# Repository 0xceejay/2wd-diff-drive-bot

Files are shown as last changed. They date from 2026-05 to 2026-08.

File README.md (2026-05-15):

# 2WD Differential Drive Bot

A work-in-progress 2-wheel differential drive robot built with ROS 2, Gazebo,
micro-ROS, and ESP32 firmware.

The project currently includes the robot description, Gazebo simulation launch
files, joystick teleoperation, a micro-ROS agent launch flow, and PlatformIO
firmware for the ESP32 controller.

## Repository layout

```text
2wd-diff-drive-bot/
|-- firmware/
|   |-- bot_firmware/        # ESP32 PlatformIO firmware
|-- src/
|   |-- bot_bringup/         # ROS 2 launch files and teleop config
|   |-- bot_description/     # URDF, xacro files, meshes, and Onshape export
|-- LICENSE
|-- README.md
```

## Main parts

| Path | Purpose |
| --- | --- |
| `src/bot_description` | Robot model, URDF/xacro files, Gazebo tags, meshes, and Onshape export workflow. |
| `src/bot_bringup` | Current launch flows for joystick teleop, micro-ROS, and Gazebo simulation. |
| `firmware/bot_firmware` | ESP32 firmware that connects to ROS 2 through micro-ROS over Wi-Fi. |

## Requirements

- ROS 2 Jazzy
- Gazebo / `ros_gz_sim` and `ros_gz_bridge`
- `xacro`
- `robot_state_publisher`
- `joy`
- `teleop_twist_joy`
- `micro_ros_agent`
- PlatformIO for the ESP32 firmware

## Build the ROS 2 workspace

From the repository root:

```bash
colcon build
source install/setup.bash
```

To build one package:

```bash
colcon build --packages-select bot_description
colcon build --packages-select bot_bringup
```

## Run simulation

```bash
source install/setup.bash
ros2 launch bot_bringup sim.launch.py
```

This starts Gazebo, publishes the robot description, spawns the robot, and
bridges the main Gazebo topics to ROS 2.

## Run the physical robot flow

Start joystick teleop and the micro-ROS agent:

```bash
source install/setup.bash
ros2 launch bot_bringup robot.launch.py
```

The ESP32 firmware must be flashed and configured with the ROS 2 computer's IP
address in `firmware/bot_firmware/include/wifi_secrets.hpp`.

## Firmware

From the repository root:

```bash
pio run -d firmware/bot_firmware
pio run -d firmware/bot_firmware --target upload
```

See `firmware/bot_firmware/README.md` for firmware setup, Wi-Fi configuration,
and micro-ROS notes.

## Documentation

- `src/bot_description/README.md`: robot description package notes.
- `src/bot_description/onshape/README.md`: Onshape export and post-processing
  workflow.
- `src/bot_bringup/README.md`: launch files and startup flows.
- `firmware/bot_firmware/README.md`: ESP32 firmware setup and commands.

## License

This project is licensed under the MIT License. See `LICENSE`.

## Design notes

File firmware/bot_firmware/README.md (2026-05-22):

# bot_firmware

PlatformIO firmware for the ESP32 controller on the 2-wheel differential drive
robot.

The firmware uses micro-ROS over Wi-Fi to connect the ESP32 to the ROS 2
computer. It subscribes to `/cmd_vel`, reads incoming
`geometry_msgs/msg/Twist` messages, and calculates left/right wheel velocity
targets from the robot geometry.

## Hardware and framework

- Board: ESP32 DOIT DevKit V1
- Framework: Arduino
- Build system: PlatformIO
- micro-ROS distro: Jazzy
- micro-ROS transport: Wi-Fi
- Serial monitor speed: `115200`
- Upload speed: `921600`
- micro-ROS agent UDP port: `8888`

These settings live in `platformio.ini`.

## Project layout

```text
bot_firmware/
|-- include/
|   |-- wifi_secrets.hpp  # Local Wi-Fi and agent IP settings
|   |-- README
|-- lib/
|   |-- Encoders/         # HC-020K wheel encoder helper
|   |-- Motors/           # TB6612FNG motor driver helper
|   |-- README
|-- src/
|   |-- main.cpp          # ESP32 micro-ROS node
|-- test/                 # PlatformIO tests
|-- platformio.ini
`-- README.md
```

## Local Wi-Fi settings

`src/main.cpp` expects a local header at:

```text
include/wifi_secrets.hpp
```

It should define:

```cpp
#define WIFI_SSID "your_wifi_name"
#define WIFI_PASSWORD "your_wifi_password"

#define AGENT_IP_1 192
#define AGENT_IP_2 168
#define AGENT_IP_3 1
#define AGENT_IP_4 10
```

The `AGENT_IP_*` values should match the IP address of the computer running the
micro-ROS agent.

Keep this file local because it contains Wi-Fi credentials.

## Build

From this folder:

```bash
pio run
```

Or from the workspace root:

```bash
pio run -d firmware/bot_firmware
```

## Upload

From this folder:

```bash
pio run --target upload
```

Or from the workspace root:

```bash
pio run -d firmware/bot_firmware --target upload
```

## Serial monitor

```bash
pio device monitor
```

The firmware prints the calculated left and right wheel velocities when it
receives `/cmd_vel` messages.

## Run with ROS 2

Start the micro-ROS agent on the ROS 2 computer:

```bash
ros2 launch bot_bringup micro_ros.launch.py
```

That launch file starts the agent with UDP on port `8888`, matching the firmware.

<!-- To start the robot bringup flow with teleop and the micro-ROS agent:

```bash
ros2 launch bot_bringup robot.launch.py
``` -->

## Subscribed topic

| Topic | Type | Purpose |
| --- | --- | --- |
| `/cmd_vel` | `geometry_msgs/msg/Twist` | Command linear and angular velocity |

The current firmware computes wheel velocity targets using:

```text
left = linear.x - (wheel_base / 2) * angular.z
right = linear.x + (wheel_base / 2) * angular.z
```

Current geometry constants:

- Wheel radius: `0.033 m`
- Wheel base: `0.1443 m`

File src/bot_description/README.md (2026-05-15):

# bot_description

ROS 2 description package for the 2-wheel differential drive robot.

This package owns the robot model used by RViz, Gazebo, and launch files in
`bot_bringup`. It contains the URDF/xacro files, mesh assets, and the Onshape
export workflow used to regenerate the model.

## Package contents

```text
bot_description/
|-- meshes/             # STL mesh assets used by the URDF
|-- onshape/            # Onshape export config and post-processing script
|-- urdf/
|   |-- bot.urdf        # Generated base URDF from Onshape
|   |-- bot.urdf.xacro  # Main robot description entry point
|   |-- gazebo.xacro    # Gazebo materials, friction, and simulation plugins
|-- CMakeLists.txt
|-- package.xml
```

## Main description file

`urdf/bot.urdf.xacro` is the entry point for the robot description.

It currently includes:

- `urdf/bot.urdf`: the generated robot links, joints, and mesh references.
- `urdf/gazebo.xacro`: Gazebo-specific materials, friction values, differential
  drive plugin configuration, and joint state publishing.

## Build

From the workspace root:

```bash
colcon build --packages-select bot_description
source install/setup.bash
```

## Run in simulation

This package provides the description assets, but the launch flow lives in
`bot_bringup`.

The usual flow is:

```bash
colcon build
source install/setup.bash
ros2 launch bot_bringup sim.launch.py
```

## Regenerate from Onshape

The base URDF and mesh assets are generated from the files in `onshape/`.

From `src/bot_description/onshape`:

```bash
onshape-to-robot . && python3 postprocess.py
```

The post-processing script copies STL files into `meshes/`, writes the processed
URDF to `urdf/bot.urdf`, simplifies selected collision geometry, and injects the
`base_link` root link.

See `onshape/README.md` for the Onshape export notes.

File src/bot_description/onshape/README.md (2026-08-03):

# Onshape export

This folder contains the files used to regenerate the robot's base URDF and
mesh assets from Onshape.

CAD assembly: [Onshape](https://cad.onshape.com/documents/292c33a7f0f854a3cdb21f44/w/3cfe75fb330dfc627e8355b6/e/a29efea0b989aa0e985d95df)

The generated files are copied into the parent `bot_description` package:

- `../urdf/bot.urdf`
- `../meshes/*.stl`

## Files

- `config.json`: configuration used by `onshape-to-robot`.
- `postprocess.py`: cleanup script that adapts the generated model for this ROS
  2 package and Gazebo simulation.

## Export workflow

Run this command from this folder:

```bash
onshape-to-robot . && python3 postprocess.py
```

`onshape-to-robot` reads `config.json`, exports the `robot` assembly from
Onshape, and creates a temporary `robot.urdf` plus an `assets/` folder.

`postprocess.py` then:

- writes the processed URDF to `../urdf/bot.urdf`
- copies exported STL files into `../meshes/`
- changes mesh paths from `assets/` to `meshes/`
- adds `base_link` as the root link with a fixed joint to `chassis`
- removes collision geometry from small/internal parts
- replaces selected collision meshes with simple box, cylinder, or sphere shapes
- adjusts wheel collision orientation and offsets
- adds light damping and friction to the caster swivel joint
- removes the temporary `robot.urdf` and `assets/` folder

## Notes

This workflow overwrites the generated URDF and refreshes mesh files in the
package. After regenerating, check the robot in simulation with:

```bash
colcon build
source install/setup.bash
ros2 launch bot_bringup sim.launch.py
```

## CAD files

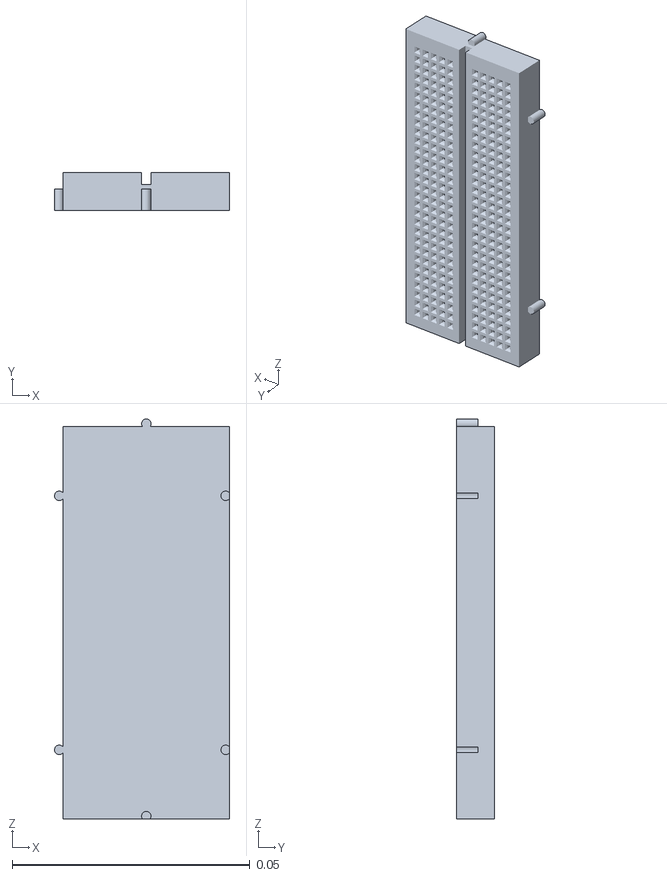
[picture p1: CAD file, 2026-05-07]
src/bot_description/meshes/main_half_size_board.stl
0.0368 x 0.008 x 0.0841

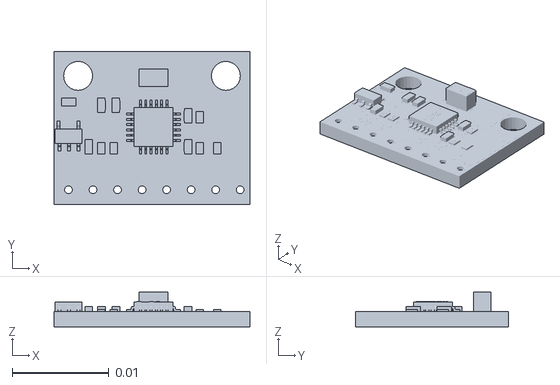
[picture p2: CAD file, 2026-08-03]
src/bot_description/meshes/mpu6050.stl
0.0203 x 0.0158 x 0.00362

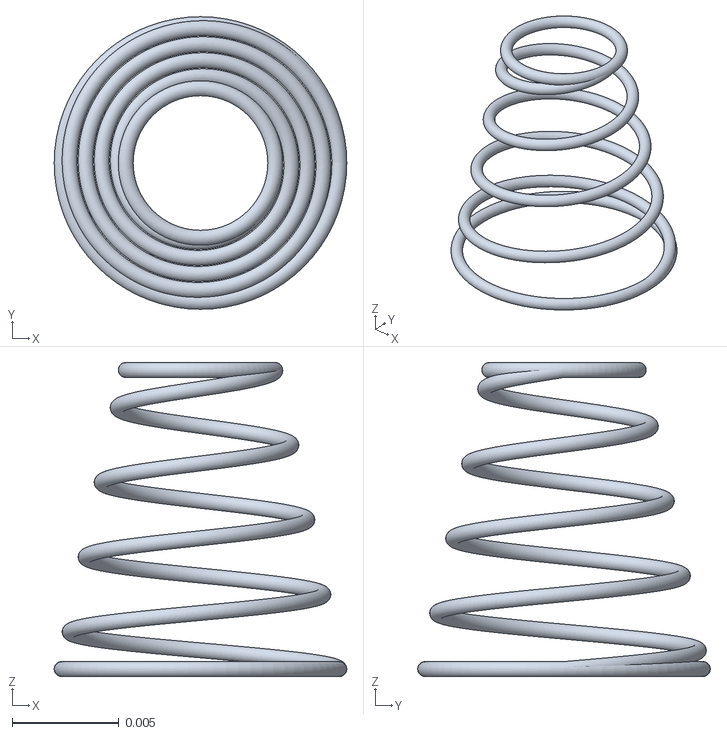
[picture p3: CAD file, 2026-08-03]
src/bot_description/meshes/contacto_helice_v2_0.stl
0.0137 x 0.0137 x 0.0147

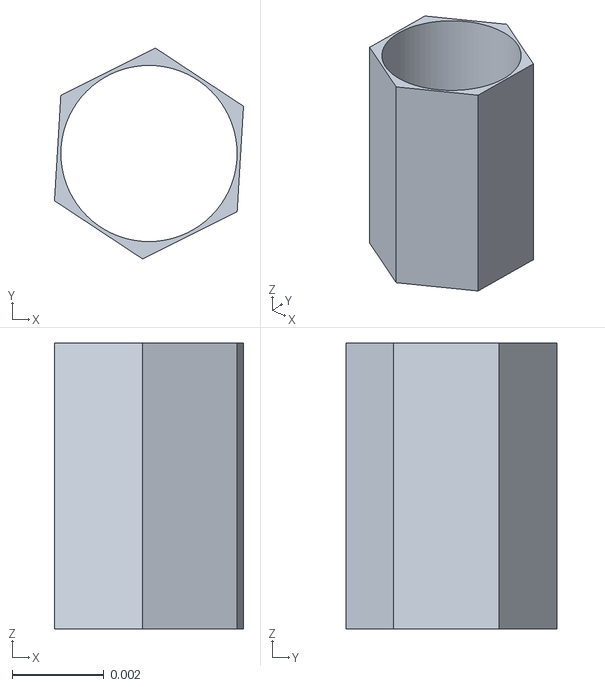
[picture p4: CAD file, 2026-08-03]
src/bot_description/meshes/spacer.stl
0.00413 x 0.00461 x 0.00625

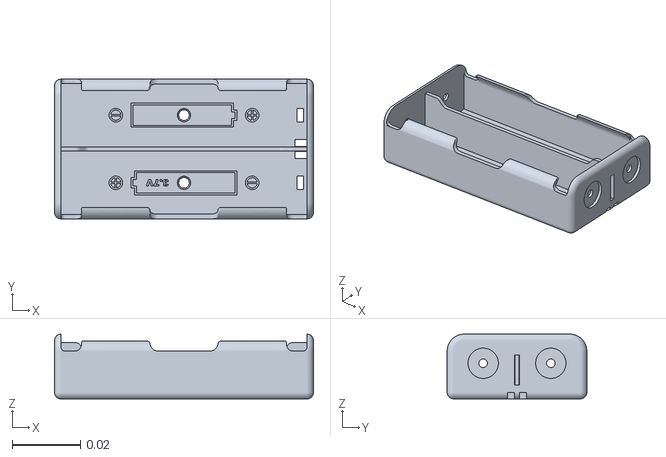
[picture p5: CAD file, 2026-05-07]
src/bot_description/meshes/porta_baterias_2x18650.stl
0.076 x 0.041 x 0.019

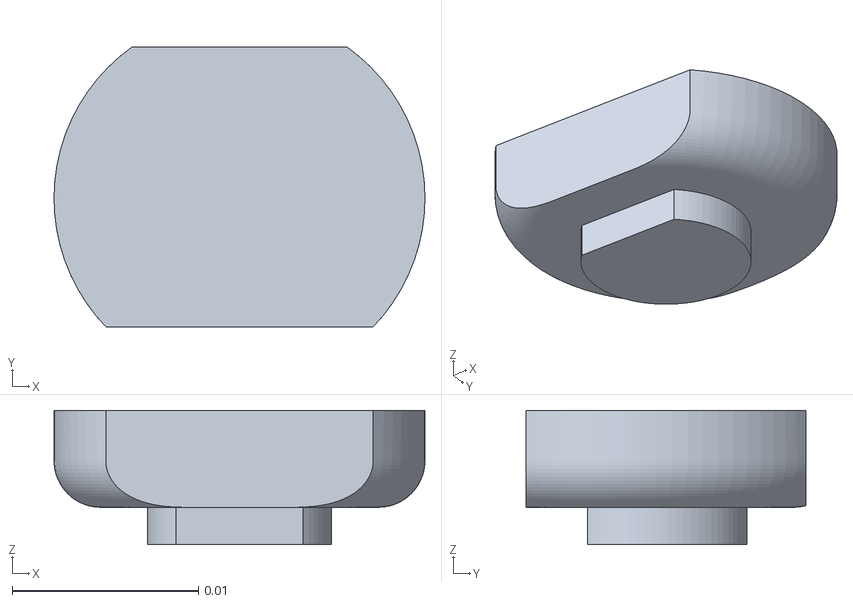
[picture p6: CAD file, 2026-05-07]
src/bot_description/meshes/tt_motor_3777_v10__6.stl
0.0199 x 0.015 x 0.0072

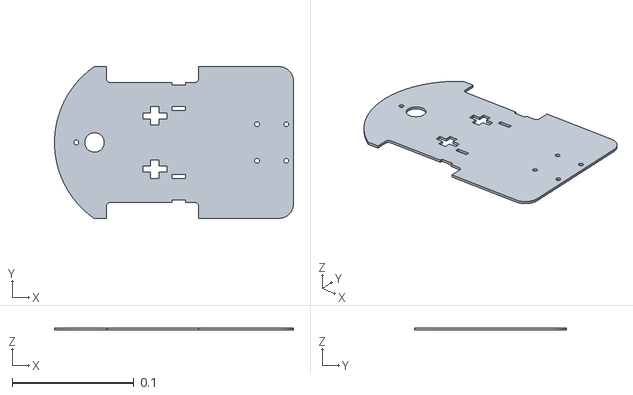
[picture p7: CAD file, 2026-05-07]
src/bot_description/meshes/chassis.stl
0.197 x 0.125 x 0.002

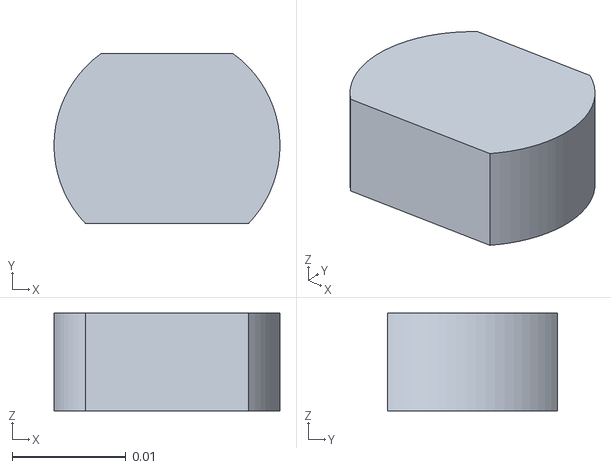
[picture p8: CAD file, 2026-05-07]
src/bot_description/meshes/tt_motor_3777_v10__4.stl
0.0199 x 0.015 x 0.0086

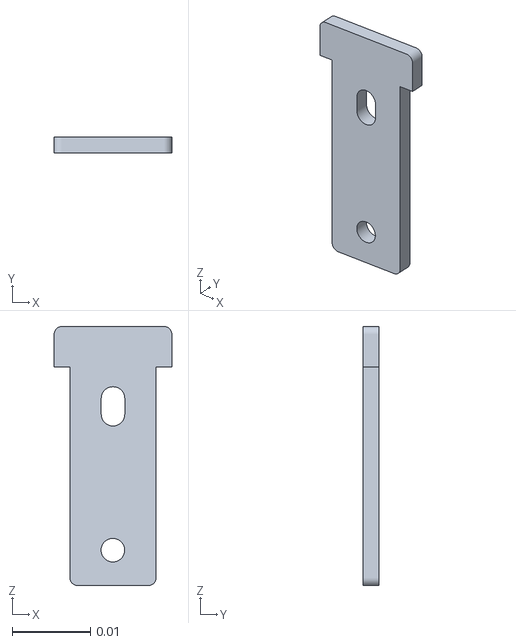
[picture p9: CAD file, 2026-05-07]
src/bot_description/meshes/motor_holders.stl
0.015 x 0.002 x 0.033

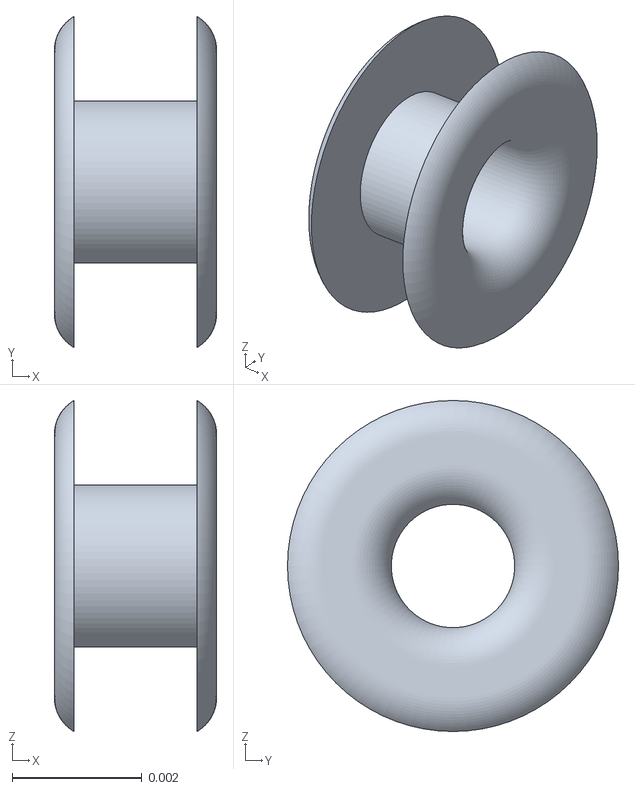
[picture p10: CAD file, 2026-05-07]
src/bot_description/meshes/remache_v1_0.stl
0.0025 x 0.0051 x 0.0051

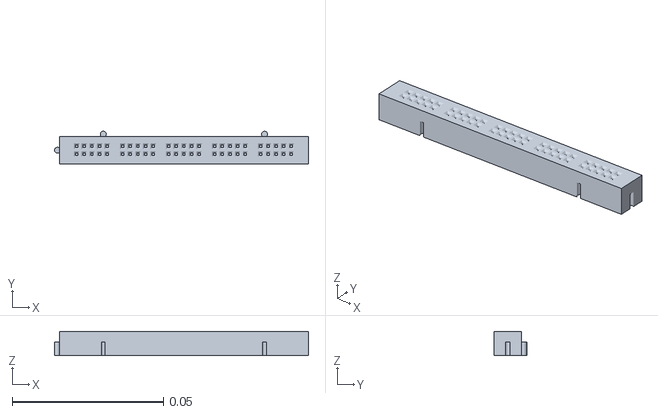
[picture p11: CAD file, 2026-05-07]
src/bot_description/meshes/half_size_side_rail.stl
0.0841 x 0.0108 x 0.008

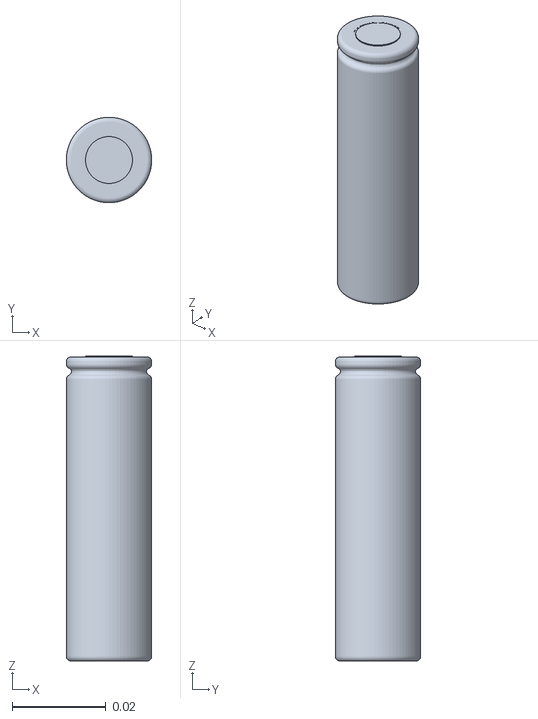
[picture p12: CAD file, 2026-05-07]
src/bot_description/meshes/bateria_18650.stl
0.0182 x 0.0182 x 0.065

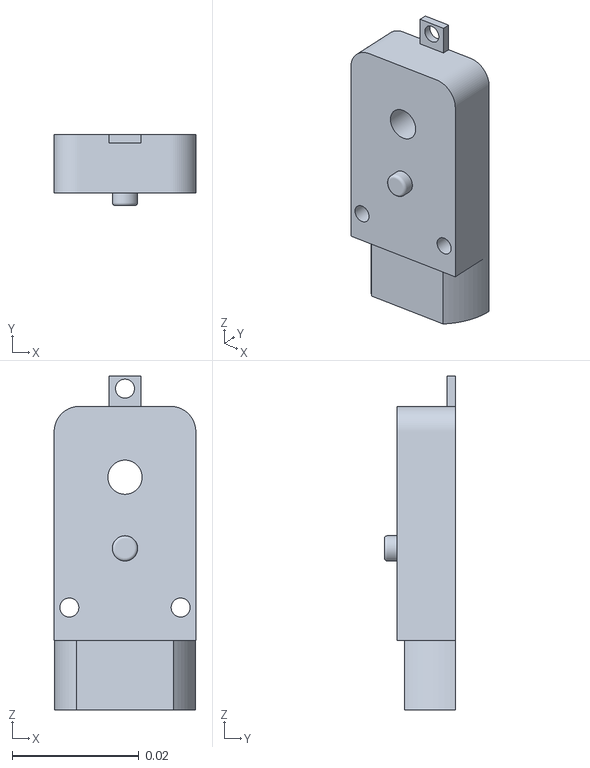
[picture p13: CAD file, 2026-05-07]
src/bot_description/meshes/tt_motor_3777_v10.stl
0.0224 x 0.0113 x 0.0528

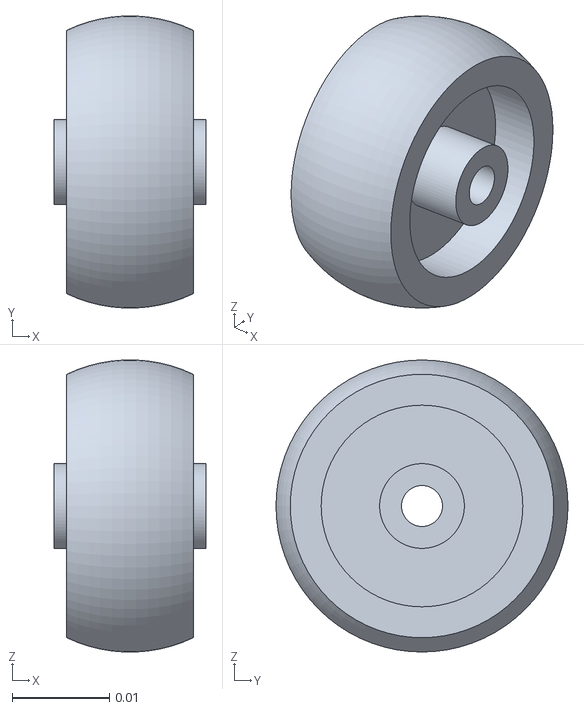
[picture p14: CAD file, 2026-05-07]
src/bot_description/meshes/caster_40mm_wheel_30mm_01.stl
0.0156 x 0.03 x 0.03

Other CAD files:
src/bot_description/meshes/tt_motor_3777_v10__3.stl
src/bot_description/meshes/tt_motor_3777_v10__2.stl
src/bot_description/meshes/tt_motor_3777_v10__5.stl
src/bot_description/meshes/caster_40mm_wheel_support_01.stl
src/bot_description/meshes/caster_40mm_swivel_plate_01.stl
src/bot_description/meshes/contacto_plano_v1_0.stl
src/bot_description/meshes/tt_motor_3777_v10__7.stl
src/bot_description/meshes/tt_motor_3777_v10__8.stl
src/bot_description/meshes/wheel.stl

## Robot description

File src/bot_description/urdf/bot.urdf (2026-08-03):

<?xml version="1.0" ?>
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
<robot name="bot">
  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
  <link name="base_link"/>
  <joint name="base_joint" type="fixed">
    <parent link="base_link"/>
    <child link="chassis"/>
  </joint>
<link name="chassis">
    <inertial>
      <origin xyz="0.0129417 0.000124462 -0.00104202" rpy="0 0 0"/>
      <mass value="0.339243"/>
      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
    </inertial>
    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
  </link>
  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
  <link name="imu_link">
    <origin xyz="0 0 0" rpy="0 -0 0"/>
    <inertial>
      <origin xyz="0 0 0" rpy="0 0 0"/>
      <mass value="1e-9"/>
      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
    </inertial>
  </link>
  <joint name="imu_link_frame" type="fixed">
    <origin xyz="0.0979786 0.033993 0.0089771" rpy="0 -0 0"/>
    <parent link="chassis"/>
    <child link="imu_link"/>
    <axis xyz="0 0 0"/>
  </joint>
  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
  <link name="wheel">
    <inertial>
      <origin xyz="0.000233615 -1.15321e-07 -0.0320156" rpy="0 0 0"/>
      <mass value="0.0449149"/>
      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
    </inertial>
    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
  </link>
  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
  <joint name="right_wheel" type="continuous">
    <origin xyz="-0.00036815 -0.0387764 -0.0135492" rpy="1.5708 -0.995712 -3.14159"/>
    <parent link="chassis"/>
    <child link="wheel"/>
    <axis xyz="0 0 1"/>
    <limit effort="10" velocity="10"/>
  </joint>
  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
  <link name="wheel_2">
    <inertial>
      <origin xyz="-0.000233615 -1.15321e-07 0.0320156" rpy="0 0 0"/>
      <mass value="0.0449149"/>
      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
    </inertial>
    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
  </link>
  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
  <joint name="left_wheel" type="continuous">
    <origin xyz="-0.00036815 0.0387236 -0.0135492" rpy="-1.5708 0 0"/>
    <parent link="chassis"/>
    <child link="wheel_2"/>
    <axis xyz="0 0 1"/>
    <limit effort="10" velocity="10"/>
  </joint>
  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
  <link name="caster_40mm_wheel_support_01">
    <inertial>
      <origin xyz="-0.000469757 -0.00666336 -0.0085057" rpy="0 0 0"/>
      <mass value="0.0177347"/>
      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
    </inertial>
    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
  </link>
  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
  <link name="caster_40mm_wheel_30mm_01">
    <inertial>
      <origin xyz="0 0 0" rpy="0 0 0"/>
      <mass value="0.007"/>
      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
    </inertial>
    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
  </link>
  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
  <joint name="caster_wheel" type="continuous">
    <origin xyz="-0 -0.0155 -0.02" rpy="1.5708 -0 1.5708"/>
    <parent link="caster_40mm_wheel_support_01"/>
    <child link="caster_40mm_wheel_30mm_01"/>
    <axis xyz="0 0 1"/>
    <limit effort="10" velocity="10"/>
  </joint>
  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
  <joint name="caster_swivel" type="revolute">
    <origin xyz="0.0967499 -2.63931e-05 -0.0129007" rpy="-0 0 1.71597"/>
    <parent link="chassis"/>
    <child link="caster_40mm_wheel_support_01"/>
    <axis xyz="0 0 1"/>
    <dynamics damping="0.01" friction="0.002"/>
    <limit effort="10" velocity="10" lower="-3.141592653589793" upper="3.141592653589793"/>
  </joint>
</robot>

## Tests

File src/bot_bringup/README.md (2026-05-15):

# bot_bringup

ROS 2 launch package for starting the 2-wheel differential drive robot.

For now, this package ties together joystick teleoperation, the micro-ROS agent,
and the Gazebo simulation launch flow. As the robot software grows, this package
will also become the place for additional launch files and startup flows. The
robot description itself lives in `bot_description`, while the ESP32 firmware
lives in `firmware/bot_firmware`.

## Package contents

```text
bot_bringup/
|-- config/
|   `-- teleop.config.yaml
|-- launch/
|   |-- micro_ros.launch.py
|   |-- robot.launch.py
|   |-- sim.launch.py
|   `-- teleop.launch.py
|-- CMakeLists.txt
|-- package.xml
`-- README.md
```

## Launch files

Current launch files:

| File | Purpose |
| --- | --- |
| `robot.launch.py` | Starts joystick teleop and the micro-ROS agent for the physical robot. |
| `teleop.launch.py` | Starts `joy_node` and `teleop_twist_joy` for joystick control. |
| `micro_ros.launch.py` | Starts the micro-ROS agent using UDP on port `8888`. |
| `sim.launch.py` | Starts Gazebo, publishes the robot description, spawns the robot, and bridges Gazebo topics to ROS 2. |

## Build

From the workspace root:

```bash
colcon build --packages-select bot_bringup
source install/setup.bash
```

## Physical robot bringup

Use this when the ESP32 firmware is flashed and connected to the same network as
the ROS 2 computer.

```bash
ros2 launch bot_bringup robot.launch.py
```

This starts:

- joystick teleoperation
- micro-ROS agent on UDP port `8888`

The ESP32 firmware should be configured with the IP address of this ROS 2
computer in `firmware/bot_firmware/include/wifi_secrets.hpp`.

## micro-ROS agent only

Use this if you want to start only the agent:

```bash
ros2 launch bot_bringup micro_ros.launch.py
```

This is useful when testing the ESP32 firmware separately from joystick teleop.

## Joystick teleop only

```bash
ros2 launch bot_bringup teleop.launch.py
```

Default launch arguments:

| Argument | Default | Purpose |
| --- | --- | --- |
| `joy_vel` | `cmd_vel` | Output velocity topic. |
| `joy_config` | `ps3` | Teleop config name used by `teleop_twist_joy`. |
| `joy_dev` | `0` | Joystick device ID. |
| `publish_stamped_twist` | `false` | Publish plain `Twist` instead of stamped `TwistStamped`. |

The local joystick config is in `config/teleop.config.yaml`.

Current control mapping:

- Linear axis: `1`
- Angular axis: `0`
- Enable button: `4`
- Turbo button: `10`

## Simulation

```bash
ros2 launch bot_bringup sim.launch.py
```

This launch file:

- starts Gazebo with `empty.sdf`
- expands `bot_description/urdf/bot.urdf.xacro`
- starts `robot_state_publisher`
- spawns the robot as `my_bot`
- bridges `/cmd_vel`, `/odom`, and `/tf` between ROS 2 and Gazebo

## Related packages

- `bot_description`: robot URDF, xacro files, meshes, and simulation tags.
- `firmware/bot_firmware`: ESP32 PlatformIO firmware that subscribes to
  `/cmd_vel` through micro-ROS.

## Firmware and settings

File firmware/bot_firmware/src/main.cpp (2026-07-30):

#include <Arduino.h>
#include <Encoders.h>
#include <IMU.h>
#include <Motors.h>
#include <micro_ros_platformio.h>

// Core ROS 2 C libraries
#include <rcl/rcl.h>
#include <rclc/rclc.h>
#include <rclc/executor.h>
#include <rmw_microros/rmw_microros.h>

#include <geometry_msgs/msg/twist.h>
#include <rosidl_runtime_c/primitives_sequence_functions.h>
#include <rosidl_runtime_c/string_functions.h>
#include <sensor_msgs/msg/imu.h>
#include <sensor_msgs/msg/joint_state.h>
#include <sensor_msgs/msg/temperature.h>

// WIFI credentials
#include "wifi_secrets.hpp"

// IP address
IPAddress agent_ip(
  AGENT_IP_1,
  AGENT_IP_2,
  AGENT_IP_3,
  AGENT_IP_4
);

// UDP port used by micro-ROS agent
size_t agent_port = 8888;

// ROS OBJECTS
rcl_allocator_t allocator;
rclc_executor_t executor;
rclc_support_t support;
rcl_subscription_t subscriber;
rcl_publisher_t imu_publisher;
rcl_publisher_t temperature_publisher;
rcl_publisher_t joint_state_publisher;
rcl_node_t node;
geometry_msgs__msg__Twist cmd_vel_msg;
sensor_msgs__msg__Imu imu_msg;
sensor_msgs__msg__Temperature temperature_msg;
sensor_msgs__msg__JointState joint_state_msg;

// Robot geometry
const float WHEEL_RADIUS = 0.033;
const float WHEEL_BASE = 0.1443;

// Wheel-speed targets calculated from the most recent /cmd_vel command.
float left_wheel_target_velocity = 0.0F;
float right_wheel_target_velocity = 0.0F;

// PWM settings
const int PWM_FREQ = 20000;

// PWM resolution in bits
// 8 bits (values from 0 to 255)
const int PWM_RESOLUTION = 8;
const int PWM_CHANNEL_A = 0;
const int PWM_CHANNEL_B = 1;

// Speed limit
const int MAX_PWM = 110;
const int MIN_MOVING_PWM = 45;
const unsigned long CMD_VEL_TIMEOUT_MS = 300;
const unsigned long IMU_READ_INTERVAL_MS = 100;
const unsigned long WHEEL_CONTROL_INTERVAL_MS = 100;
const unsigned long ENCODER_PUBLISH_INTERVAL_MS = 100;
const float TWO_PI_F = 6.28318530718F;
const float ENCODER_PULSES_PER_REVOLUTION = 20.0F;
const float MAX_WHEEL_SPEED_MPS = 0.5F;
const float STOPPED_VELOCITY_THRESHOLD_MPS = 0.005F;

// Initial velocity-controller gains.
const float WHEEL_PID_KP = 80.0F;
const float WHEEL_PID_KI = 30.0F;
const float WHEEL_PID_KD = 2.0F;
const float WHEEL_PID_INTEGRAL_LIMIT = 1.0F;

struct WheelPIDState
{
  float integral;
  float previous_error;
  bool has_previous_error;
};

MotorPins motor_pins = {
  25, // PWMA
  26, // AIN1
  27, // AIN2
  13, // PWMB
  33, // BIN1
  32, // BIN2
  14  // STBY
};

Motors motors(
  motor_pins,
  PWM_FREQ,
  PWM_RESOLUTION,
  PWM_CHANNEL_A,
  PWM_CHANNEL_B
);

Encoders encoders(
  34,  // Left HC-020K encoder pin
  35,  // Right HC-020K encoder pin
  (int)ENCODER_PULSES_PER_REVOLUTION
);

// The ESP32's default I2C pins are GPIO 21 (SDA) and GPIO 22 (SCL).
MyIMU imu;
IMUReading imu_reading;

// Timestamp of last received /cmd_vel message
unsigned long last_cmd_vel_ms = 0;
unsigned long last_imu_read_ms = 0;
unsigned long last_wheel_control_ms = 0;
unsigned long last_encoder_publish_ms = 0;

// Flag to track if we've received at least one /cmd_vel message
bool has_received_cmd_vel = false;
bool imu_available = false;
bool encoder_reading_available = false;

WheelPIDState left_wheel_pid = {0.0F, 0.0F, false};
WheelPIDState right_wheel_pid = {0.0F, 0.0F, false};
EncoderReading latest_encoder_reading = {0, 0, 0.0F, 0.0F};

// Stop the motors and halt execution after an unrecoverable startup failure.
void stopOnFatalError()
{
  motors.stop();

  while (true)
  {
    delay(1000);
  }
}

// Stamp a ROS message with synchronized agent time or local uptime as fallback.
void setMessageTimestamp(std_msgs__msg__Header & header)
{
  int64_t timestamp_ns = rmw_uros_epoch_nanos();

  // Fall back to time since boot if session time synchronization failed.
  if (timestamp_ns <= 0)
  {
    timestamp_ns = (int64_t)millis() * 1000000LL;
  }

  header.stamp.sec = (int32_t)(timestamp_ns / 1000000000LL);
  header.stamp.nanosec = (uint32_t)(timestamp_ns % 1000000000LL);
}

// Raise nonzero PWM commands to the minimum value that can move a wheel.
int applyMinimumMovingPwm(int pwm)
{
  if (pwm == 0)
  {
    return 0;
  }

  if (abs(pwm) < MIN_MOVING_PWM)
  {
    return pwm > 0 ? MIN_MOVING_PWM : -MIN_MOVING_PWM;
  }

  return pwm;
}

// Clear accumulated error and derivative history for one wheel controller.
void resetWheelPID(WheelPIDState & state)
{
  state.integral = 0.0F;
  state.previous_error = 0.0F;
  state.has_previous_error = false;
}

// Convert a wheel-velocity error into a bounded feed-forward plus PID command.
int calculateWheelPwm(
  float target_velocity,
  float measured_velocity,
  float dt,
  WheelPIDState & state
)
{
  // A zero target uses active braking and clears accumulated controller state.
  if (abs(target_velocity) < STOPPED_VELOCITY_THRESHOLD_MPS)
  {
    resetWheelPID(state);
    return 0;
  }

  float error = target_velocity - measured_velocity;

  // Clamp the integral term to prevent wind-up while the output is saturated.
  state.integral += error * dt;
  state.integral = constrain(
    state.integral,
    -WHEEL_PID_INTEGRAL_LIMIT,
    WHEEL_PID_INTEGRAL_LIMIT
  );

  float derivative = 0.0F;

  if (state.has_previous_error && dt > 0.0F)
  {
    derivative = (error - state.previous_error) / dt;
  }

  state.previous_error = error;
  state.has_previous_error = true;

  // Feed-forward supplies the approximate steady-state PWM. PID then corrects
  // for battery voltage, motor mismatch, load, and floor-friction changes.
  float feedforward =
    (target_velocity / MAX_WHEEL_SPEED_MPS) * MAX_PWM;
  float correction =
    WHEEL_PID_KP * error +
    WHEEL_PID_KI * state.integral +
    WHEEL_PID_KD * derivative;
  float requested_pwm = feedforward + correction;

  // Do not command the wheel to reverse merely to correct a brief overspeed.
  if (target_velocity > 0.0F)
  {
    requested_pwm = constrain(requested_pwm, 0.0F, (float)MAX_PWM);
  }
  else
  {
    requested_pwm = constrain(requested_pwm, (float)-MAX_PWM, 0.0F);
  }

  return applyMinimumMovingPwm((int)requested_pwm);
}

// Sample both encoders and update the closed-loop motor commands periodically.
void updateWheelVelocityControl()
{
  unsigned long current_time_ms = millis();
  unsigned long elapsed_ms = current_time_ms - last_wheel_control_ms;

  if (elapsed_ms < WHEEL_CONTROL_INTERVAL_MS)
  {
    return;
  }

  last_wheel_control_ms = current_time_ms;
  float dt = elapsed_ms / 1000.0F;

  // One encoder sample drives both the controller and the ROS publication.
  latest_encoder_reading = encoders.read();
  encoder_reading_available = true;

  float left_measured_velocity =
    latest_encoder_reading.left_rpm * TWO_PI_F * WHEEL_RADIUS / 60.0F;
  float right_measured_velocity =
    latest_encoder_reading.right_rpm * TWO_PI_F * WHEEL_RADIUS / 60.0F;

  int left_pwm = calculateWheelPwm(
    left_wheel_target_velocity,
    left_measured_velocity,
    dt,
    left_wheel_pid
  );
  int right_pwm = calculateWheelPwm(
    right_wheel_target_velocity,
    right_measured_velocity,
    dt,
    right_wheel_pid
  );

  // Single-channel encoders need the commanded direction to sign each pulse.
  encoders.setDirections(left_pwm, right_pwm);
  motors.setLeft(left_pwm);
  motors.setRight(right_pwm);
}

// Read and publish acceleration, angular velocity, and temperature periodically.
void readAndPublishIMU()
{
  if (!imu_available)
  {
    return;
  }

  unsigned long current_time_ms = millis();

  if (current_time_ms - last_imu_read_ms < IMU_READ_INTERVAL_MS)
  {
    return;
  }

  last_imu_read_ms = current_time_ms;

  if (!imu.readIMU(imu_reading))
  {
    return;
  }

  setMessageTimestamp(imu_msg.header);
  temperature_msg.header.stamp = imu_msg.header.stamp;

  imu_msg.linear_acceleration.x = imu_reading.acceleration_x;
  imu_msg.linear_acceleration.y = imu_reading.acceleration_y;
  imu_msg.linear_acceleration.z = imu_reading.acceleration_z;
  imu_msg.angular_velocity.x = imu_reading.angular_velocity_x;
  imu_msg.angular_velocity.y = imu_reading.angular_velocity_y;
  imu_msg.angular_velocity.z = imu_reading.angular_velocity_z;
  temperature_msg.temperature = imu_reading.temperature;

  if (rcl_publish(&imu_publisher, &imu_msg, NULL) != RCL_RET_OK)
  {
    return;
  }

  if (rcl_publish(
        &temperature_publisher,
        &temperature_msg,
        NULL
      ) != RCL_RET_OK)
  {
    return;
  }
}

// Publish the latest encoder-derived wheel positions and angular velocities.
void readAndPublishEncoders()
{
  unsigned long current_time_ms = millis();

  if (!encoder_reading_available ||
      current_time_ms - last_encoder_publish_ms <
        ENCODER_PUBLISH_INTERVAL_MS)
  {
    return;
  }

  last_encoder_publish_ms = current_time_ms;

  setMessageTimestamp(joint_state_msg.header);

  joint_state_msg.position.data[0] =
    (latest_encoder_reading.left_ticks / ENCODER_PULSES_PER_REVOLUTION) *
    TWO_PI_F;
  joint_state_msg.position.data[1] =
    (latest_encoder_reading.right_ticks / ENCODER_PULSES_PER_REVOLUTION) *
    TWO_PI_F;

  joint_state_msg.velocity.data[0] =
    latest_encoder_reading.left_rpm * TWO_PI_F / 60.0F;
  joint_state_msg.velocity.data[1] =
    latest_encoder_reading.right_rpm * TWO_PI_F / 60.0F;

  if (rcl_publish(
        &joint_state_publisher,
        &joint_state_msg,
        NULL
      ) != RCL_RET_OK)
  {
    return;
  }
}

// Allocate message storage and populate fixed frame and joint metadata.
void initializeMessages()
{
  if (!geometry_msgs__msg__Twist__init(&cmd_vel_msg) ||
      !sensor_msgs__msg__Imu__init(&imu_msg) ||
      !sensor_msgs__msg__Temperature__init(&temperature_msg) ||
      !sensor_msgs__msg__JointState__init(&joint_state_msg))
  {
    stopOnFatalError();
  }

  if (!rosidl_runtime_c__String__assign(&imu_msg.header.frame_id, "base_link") ||
      !rosidl_runtime_c__String__assign(
        &temperature_msg.header.frame_id,
        "base_link"
      ) ||
      !rosidl_runtime_c__String__Sequence__init(&joint_state_msg.name, 2) ||
      !rosidl_runtime_c__double__Sequence__init(
        &joint_state_msg.position,
        2
      ) ||
      !rosidl_runtime_c__double__Sequence__init(
        &joint_state_msg.velocity,
        2
      ))
  {
    stopOnFatalError();
  }

  if (!rosidl_runtime_c__String__assign(
        &joint_state_msg.name.data[0],
        "left_wheel"
      ) ||
      !rosidl_runtime_c__String__assign(
        &joint_state_msg.name.data[1],
        "right_wheel"
      ))
  {
    stopOnFatalError();
  }

  // The MPU6050 wrapper does not calculate orientation.
  imu_msg.orientation_covariance[0] = -1.0;
}

// Convert each received velocity command into left and right wheel targets.
void cmd_vel_callback(const void * msgin)
{
  // Cast incoming generic pointer to Twist message type
  const geometry_msgs__msg__Twist * twist_msg =
    (const geometry_msgs__msg__Twist *)msgin;

  float linear_velocity = twist_msg->linear.x;
  float angular_velocity = twist_msg->angular.z;

  left_wheel_target_velocity =
    linear_velocity - (WHEEL_BASE / 2.0F) * angular_velocity;
  right_wheel_target_velocity =
    linear_velocity + (WHEEL_BASE / 2.0F) * angular_velocity;

  // Keep target speeds inside the range used by the feed-forward model.
  left_wheel_target_velocity = constrain(
    left_wheel_target_velocity,
    -MAX_WHEEL_SPEED_MPS,
    MAX_WHEEL_SPEED_MPS
  );
  right_wheel_target_velocity = constrain(
    right_wheel_target_velocity,
    -MAX_WHEEL_SPEED_MPS,
    MAX_WHEEL_SPEED_MPS
  );

  last_cmd_vel_ms = millis();
  has_received_cmd_vel = true;

}

// Initialize hardware, micro-ROS transport, messages, and ROS entities once.
void setup()
{
  // Initialize motor driver and wheel encoders
  motors.begin();
  encoders.begin();

  // Ensure motors are stopped at startup
  motors.stop();
  encoders.setDirections(0, 0);

  // Initialize the MPU6050 before networking. The robot must remain stationary
  // while the gyro bias is measured.
  if (!imu.setupIMU())
  {
    imu_available = false;
  }
  else
  {
    if (imu.calibrateGyro())
    {
      imu_available = true;
    }
    else
    {
      imu_available = false;
    }
  }

  // Configure WiFi transport for micro-ROS
  set_microros_wifi_transports(
    WIFI_SSID,
    WIFI_PASSWORD,
    agent_ip,
    agent_port
  );

  delay(2000);

  // Initialize allocator
  allocator = rcl_get_default_allocator();

  // Initialize ROS support structure
  rclc_support_init(&support, 0, NULL, &allocator);

  // Create ROS Node
  rclc_node_init_default(&node, "esp32_node", "", &support);

  initializeMessages();

  // Create subscriber for /cmd_vel
  rclc_subscription_init_best_effort(
    &subscriber,
    &node,

    // Message type
    ROSIDL_GET_MSG_TYPE_SUPPORT(
      geometry_msgs,
      msg,
      Twist
    ),

    // Topic name
    "/cmd_vel"
  );

  rclc_publisher_init_best_effort(
    &imu_publisher,
    &node,
    ROSIDL_GET_MSG_TYPE_SUPPORT(sensor_msgs, msg, Imu),
    "/imu/data_raw"
  );

  rclc_publisher_init_best_effort(
    &temperature_publisher,
    &node,
    ROSIDL_GET_MSG_TYPE_SUPPORT(sensor_msgs, msg, Temperature),
    "/imu/temperature"
  );

  rclc_publisher_init_best_effort(
    &joint_state_publisher,
    &node,
    ROSIDL_GET_MSG_TYPE_SUPPORT(sensor_msgs, msg, JointState),
    "/joint_states"
  );

  // Synchronize message timestamps with the ROS computer.
  rmw_uros_sync_session(1000);

  // Initializw executor
  rclc_executor_init(&executor, &support.context, 1, &allocator);

  // Add subscriber callback to executor
  rclc_executor_add_subscription(
    &executor,
    &subscriber,
    &cmd_vel_msg,
    &cmd_vel_callback,

    // Trigger callback only when new data arrives
    ON_NEW_DATA
  );

}

// Service ROS work, update sensors and motors, and enforce command timeout.
void loop()
{
  rclc_executor_spin_some(
    &executor,

    // Max processing time
    RCL_MS_TO_NS(10)
  );

  delay(10);

  // Run closed-loop wheel control before publishing its latest measurement.
  updateWheelVelocityControl();
  readAndPublishEncoders();
  readAndPublishIMU();

  // Stop motors if no cmd_vel message received within timeout period
  if (has_received_cmd_vel && millis() - last_cmd_vel_ms > CMD_VEL_TIMEOUT_MS)
  {
    left_wheel_target_velocity = 0.0F;
    right_wheel_target_velocity = 0.0F;
    resetWheelPID(left_wheel_pid);
    resetWheelPID(right_wheel_pid);
    encoders.setDirections(0, 0);
    motors.stop();
    has_received_cmd_vel = false;
  }
}

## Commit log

2026-05-07 bot_description package
    [bateria_18650.stl, caster_40mm_swivel_plate_01.stl, caster_40mm_wheel_30mm_01.stl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]
2026-05-07 repair collision boundaries
    [bot.urdf]
2026-05-07 reduced spacers and added dummy_link
    [bot.urdf, spacer.stl]
2026-05-07 added differential drive and joint state publisher plugins
    [gazebo.xacro]
2026-05-09 wifi password for esp32
2026-05-11 corrected wheel seperation
    [gazebo.xacro]
2026-05-11 right and left wheel velocity calculations
2026-05-22 Add encoder and motor libraries and update firmware
2026-07-30 IMU code
2026-07-30 Successfully added IMU and code for PID
2026-08-03 Added mpu6050 to CAD and URDF
    [bot.urdf, contacto_helice_v2_0.stl, mpu6050.stl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]
2026-08-03 friction for swivel joint
    [bot.urdf, gazebo.xacro]
